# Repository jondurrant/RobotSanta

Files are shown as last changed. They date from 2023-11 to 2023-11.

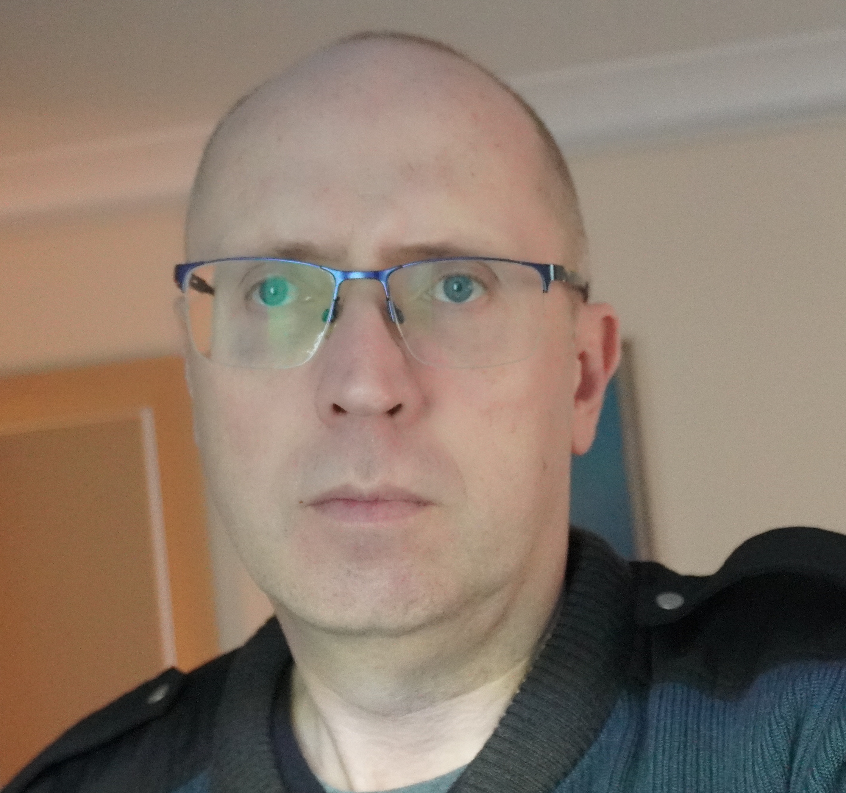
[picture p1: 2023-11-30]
py/Images/Jon.JPG

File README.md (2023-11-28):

# RobotSanta

This is a face tracking Santa Head project for my [YouTube channel](https://youtube.com/@drjonea). Built using a Raspberry PI 4 and Raspberry PI Pico.

## Cloning
Please clone with the *--recurse-submodules* switch to include the libraries.

## Pico - Firmware

This is dependent on three libraries:
+ [MicroROS](https://github.com/micro-ROS/micro_ros_raspberrypi_pico_sdk) - Allow Pico to see and communicate with ROS Nodes
+ [FreeRTOS Kernel](https://github.com/FreeRTOS/FreeRTOS-Kernel) - Allow multi threading tasks on Pico
+ [Eigen](https://gitlab.com/libeigen/eigen) - Used to do some Robot maths

To build binary
```
mkdir build
cd build
cmake ..
make
```

### RPI - High-level function

The Raspberry PI needs to be running MicroROS bridget to connect to the Pico.  See the repo [MicroROS](https://github.com/micro-ROS/micro_ros_raspberrypi_pico_sdk) or my [video walkthrough on MicroROS](https://youtu.be/2dGCcT9rxso)

You will also need to install [ROS Humble](https://docs.ros.org/en/humble/Installation.html).

The *py* folder contains two python programms.

## pose.py
This will instruct the head to move to a possition. It takes pitch and yaw as parameters in radians. (-PI/2 to PI/2).

## facePan.py
This uses openCV to detect faces on a camera and instruct the Robot to turn towards that face.

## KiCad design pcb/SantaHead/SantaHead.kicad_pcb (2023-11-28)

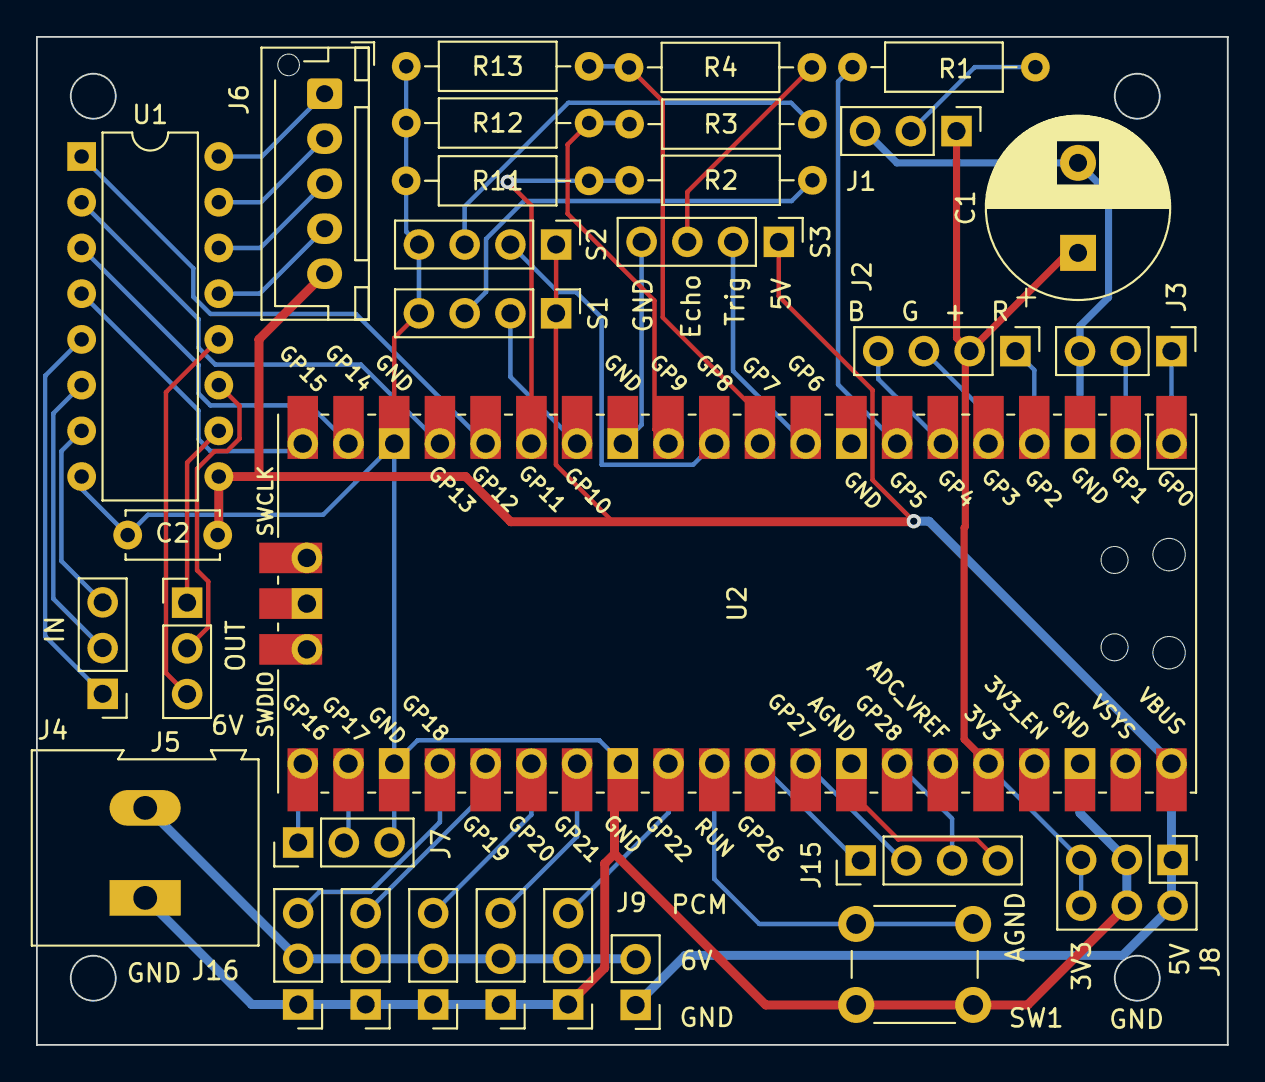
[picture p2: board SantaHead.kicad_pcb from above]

Board: 2 copper layers, 66.2 x 56.0 mm, 31 parts (0 on the bottom side), 46 nets.

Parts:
C1: C_Polarized; CP_Radial_D10.0mm_P5.00mm
C2: 100nF; C_Disc_D5.0mm_W2.5mm_P5.00mm
J1, J3, J4, J5, J7, J10, J11, J12, J13, J14: Conn_01x03_Male; PinHeader_1x03_P2.54mm_Vertical
J2, J15: Conn_01x04_Male; PinHeader_1x04_P2.54mm_Vertical
J6: Conn_01x05; JST_XH_B5B-XH-AM_1x05_P2.50mm_Vertical
J8: Conn_02x03_Odd_Even; PinHeader_2x03_P2.54mm_Vertical
J9: Conn_01x02_Male; PinHeader_1x02_P2.54mm_Vertical
J16: Screw_Terminal_01x02; TerminalBlock_Altech_AK300-2_P5.00mm
R1: 220R; R_Axial_DIN0207_L6.3mm_D2.5mm_P10.16mm_Horizontal
R2, R3, R4: 2K2; R_Axial_DIN0207_L6.3mm_D2.5mm_P10.16mm_Horizontal
R11, R12, R13: 3k3; R_Axial_DIN0207_L6.3mm_D2.5mm_P10.16mm_Horizontal
S1, S2, S3: HCSR04; PinHeader_1x04_P2.54mm_Vertical
SW1: SW_Push; SW_PUSH_6mm
U1: ULN2003; DIP-16_W7.62mm
U2: Pico; RPi_Pico_SMD_TH

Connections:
+3.3V: C1.1, J1.1, J2.2, J8.5, J8.6, U2.36 (3V3)
+5V: C2.1, J6.5, J8.1, J8.2, J9.1, S1.1 (VCC), S2.1 (VCC), S3.1 (VCC), U1.9 (COM), U2.40 (VBUS)
+6V: J9.2, J10.2, J11.2, J12.2, J13.2, J14.2, J16.2
GND: C1.2, C2.2, J1.3, J3.3, J7.3, J8.3, J8.4, J10.1, J11.1, J12.1, J13.1, J14.1, J16.1, R11.2, R12.2, R13.2, S1.4 (GND), S2.4 (GND), S3.4 (GND), SW1.2, U1.8 (GND), U2.3 (GND), U2.13 (GND), U2.18 (GND), U2.23 (GND), U2.28 (GND), U2.38 (GND)
unnamed: J1.2, R1.1
unnamed: J2.1, U2.4 (GPIO2)
unnamed: J2.3, U2.5 (GPIO3)
unnamed: J2.4, U2.6 (GPIO4)
unnamed: J3.1, U2.1 (GPIO0)
unnamed: J3.2, U2.2 (GPIO1)
unnamed: J6.1, U1.16 (O1)
unnamed: J6.2, U1.15 (O2)
unnamed: J6.3, U1.14 (O3)
unnamed: J6.4, U1.13 (O4)
unnamed: J10.3, U2.29 (GPIO22)
unnamed: J11.3, U2.27 (GPIO21)
unnamed: J12.3, U2.26 (GPIO20)
unnamed: J13.3, U2.25 (GPIO19)
unnamed: J14.3, U2.24 (GPIO18)
unnamed: J15.1 (VCC), U2.31 (GPIO26_ADC0)
unnamed: J15.3 (ECHO), U2.34 (GPIO28_ADC2)
unnamed: R1.2, U2.7 (GPIO5)
unnamed: R2.1, S1.3 (ECHO)
unnamed: R3.1, S2.3 (ECHO)
unnamed: R4.1, S3.3 (ECHO)
unnamed: R2.2, R11.1, U2.15 (GPIO11)
unnamed: R3.2, R12.1, U2.12 (GPIO9)
unnamed: R4.2, R13.1, U2.10 (GPIO7)
unnamed: S1.2 (TRIG), U2.14 (GPIO10)
unnamed: S2.2 (TRIG), U2.11 (GPIO8)
unnamed: S3.2 (TRIG), U2.9 (GPIO6)
unnamed: SW1.1, U2.30 (RUN)
unnamed: J4.1, U1.5 (I5)
unnamed: J4.2, U1.6 (I6)
unnamed: J4.3, U1.7 (I7)
unnamed: J5.1, U1.10 (O7)
unnamed: J5.2, U1.11 (O6)
unnamed: J5.3, U1.12 (O5)
unnamed: U1.1 (I1), U2.16 (GPIO12)
unnamed: U1.2 (I2), U2.17 (GPIO13)
unnamed: U1.3 (I3), U2.19 (GPIO14)
unnamed: U1.4 (I4), U2.20 (GPIO15)
unnamed: J7.1, U2.21 (GPIO16)
unnamed: J7.2, U2.22 (GPIO17)
unnamed: J15.2 (TRIG), U2.32 (GPIO27_ADC1)
unnamed: J15.4 (GND), U2.33 (AGND)

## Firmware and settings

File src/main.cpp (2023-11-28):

/***
 * main.cpp - HTTP Get over socket
 * Jon Durrant
 * 4-Oct-2022
 *
 *
 */

#include "pico/stdlib.h"
#include <stdio.h>

#include "FreeRTOS.h"
#include "task.h"
#include <stdio.h>

#include "EyesAgent.h"
#include "Head.h"

#include "uRosBridge.h"
#include "HeadEntities.h"
#include "Eyes.h"

extern"C"{
#include "pico/stdio/driver.h"
#include "pico/stdio.h"
#include "pico/stdio_usb.h"
#include "pico/stdio_uart.h"
}




#define TASK_PRIORITY      ( tskIDLE_PRIORITY + 1UL )
#define LED_PAD 18


void runTimeStats(){
  TaskStatus_t         * pxTaskStatusArray;
  volatile UBaseType_t uxArraySize, x;
  unsigned long        ulTotalRunTime;


  /* Take a snapshot of the number of tasks in case it changes while this
  function is executing. */
  uxArraySize = uxTaskGetNumberOfTasks();
  printf("Number of tasks %d\n", uxArraySize);

  /* Allocate a TaskStatus_t structure for each task.  An array could be
  allocated statically at compile time. */
  pxTaskStatusArray = (TaskStatus_t*) pvPortMalloc(uxArraySize * sizeof(TaskStatus_t));

  if (pxTaskStatusArray != NULL){
    /* Generate raw status information about each task. */
    uxArraySize = uxTaskGetSystemState(pxTaskStatusArray,
                                       uxArraySize,
                                       &ulTotalRunTime);



    /* For each populated position in the pxTaskStatusArray array,
    format the raw data as human readable ASCII data. */
    for (x = 0; x < uxArraySize; x++){
      printf("Task: %d \t cPri:%d \t bPri:%d \t hw:%d \t%s\n",
             pxTaskStatusArray[x].xTaskNumber,
             pxTaskStatusArray[x].uxCurrentPriority,
             pxTaskStatusArray[x].uxBasePriority,
             pxTaskStatusArray[x].usStackHighWaterMark,
             pxTaskStatusArray[x].pcTaskName
      );
    }


    /* The array is no longer needed, free the memory it consumes. */
    vPortFree(pxTaskStatusArray);
  } else{
    printf("Failed to allocate space for stats\n");
  }

  HeapStats_t heapStats;
  vPortGetHeapStats(&heapStats);
  printf("HEAP avl: %d, blocks %d, alloc: %d, free: %d\n",
         heapStats.xAvailableHeapSpaceInBytes,
         heapStats.xNumberOfFreeBlocks,
         heapStats.xNumberOfSuccessfulAllocations,
         heapStats.xNumberOfSuccessfulFrees
  );

}


void main_task(void* params){
  Head head(22, 21);  //(20, 19);
  EyesAgent eyes(2,3,4);

  HeadEntities entities(&head, &eyes);
  eyes.setColour(255,0,0);

  printf("Main task started\n");


  head.start("Head", TASK_PRIORITY);
  eyes.start("Eyes", TASK_PRIORITY);


    //Start up a uROS Bridge
	uRosBridge *bridge = uRosBridge::getInstance();

	bridge->setLed(LED_PAD);
	bridge->setuRosEntities(&entities);
	bridge->start("Bridge",  TASK_PRIORITY+2);


  for(;;){

	  for (int i=0; i < 5; i++){

		  vTaskDelay(3000);
	  }


    //runTimeStats();


    vTaskDelay(1000);



    }

}


void vLaunch(void) {
  TaskHandle_t task;

  xTaskCreate(main_task, "MainThread", 2048, NULL, TASK_PRIORITY, &task);

  /* Start the tasks and timer running. */
  vTaskStartScheduler();
}


int main(void) {
  stdio_init_all();
  stdio_filter_driver(&stdio_uart);
  sleep_ms(2000);
  printf("GO\n");

  /* Configure the hardware ready to run the demo. */
  const char* rtos_name;
  rtos_name = "FreeRTOS";
  printf("Starting %s on core 0:\n", rtos_name);
  vLaunch();

  return 0;
}

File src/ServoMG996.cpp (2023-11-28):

/*
 * ServoMG996.cpp
 *
 *  Created on: 9 Nov 2023
 *      Author: jondurrant
 */

#include "ServoMG996.h"
#include "hardware/pwm.h"
#include "hardware/clocks.h"
#include <stdio.h>

ServoMG996::ServoMG996() {
	xGP=0xFF;

}

ServoMG996::ServoMG996(uint8_t gp){
	setGP(gp);
}

ServoMG996::~ServoMG996(){
	//NOP
}


/***
* Set GPIO Pad
* @param gp
*/
void ServoMG996::setGP(uint8_t gp){
	xGP = gp;

	gpio_init(gp);

	//Setup up PWM t
	gpio_set_function(gp, GPIO_FUNC_PWM);
	pwm_set_gpio_level(gp, 0);
	uint slice_num = pwm_gpio_to_slice_num(gp);

	// Get clock speed and compute divider for 50 hz
	uint32_t clk = clock_get_hz(clk_sys);
	uint32_t div = clk / (20000 * 50);

	// Check div is in range
	if ( div < 1 ){
		div = 1;
	}
	if ( div > 255 ){
		div = 255;
	}

	pwm_config config = pwm_get_default_config();
	pwm_config_set_clkdiv(&config, (float)div);

	// Set wrap so the period is 20 ms
	pwm_config_set_wrap(&config, 20000);

	// Load the configuration
	pwm_init(slice_num, &config, false);

	pwm_set_enabled(slice_num, true);

	printf("Servo(%u) slicer %u\n", xGP, slice_num);

	goRad(xRad);
}

/**
* move to angle
* @param radians  -PI/2 to PI/2
*/
void ServoMG996::goRad(double radians){
	int duty = xDutyZero;
	if (xGP > 28){
		return;
	}
	if (radians > M_PI/2){
		return;
	}
	if (radians < M_PI/(-2)){
		return;
	}


	if (radians > 0.0){
		duty = ((xDutyPos - xDutyZero)/ (M_PI/2)) * radians + xDutyZero;
	}
	if (radians < 0.0){
		double rad = radians + M_PI/2;
		duty = ((xDutyZero - xDutyNeg)/ (M_PI/2)) * rad + xDutyNeg;
	}

	//printf("PWM for %f rad is %d duty\n", radians, duty);
	pwm_set_gpio_level(xGP, duty);
	xRad = radians;
}

/***
 * Get current angle
 * @return
 */
double ServoMG996::getRad(){
	return xRad;
}

/***
* Turn servo off
*/
void ServoMG996::off(){
	pwm_set_gpio_level(xGP, 0);
}

/***
 * Adjust the duty cycle for the set points by delta
 * @param neg - delta adjustment for RAD PI/(-2)
 * @param zero - delta adjustment for RAD 0.0
 * @param pos - delta adjustment for RAD PI/2
 */
void ServoMG996::adjustDuty(int neg, int zero, int pos){
	if (( neg + xDutyNeg) > 0){
		xDutyNeg+=neg;
	}
	if (( zero + xDutyZero) > 0){
		xDutyZero+=zero;
	}
	if (( pos + xDutyPos) > 0){
		xDutyPos+=pos;
	}
}
